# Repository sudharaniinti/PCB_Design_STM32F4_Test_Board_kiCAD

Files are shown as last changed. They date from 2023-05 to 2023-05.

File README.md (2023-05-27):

# STM32F4_based_PCB_Design_using_kiCAD
This repository contains all the files related to the design of a PCB using KICAD. The PCB is based on the STM32F4-based microcontroller and incorporates a USB interface and a Buck converter.

This repository includes the following files:

1. **Schematic (PDF File)**: A detailed PDF file that presents the circuit connections and component arrangement in a clear and concise manner.

2. **Schematic (kiCAD File)**: The original KICAD file of the schematic, allowing for easy editing and customization.

3. **Netlist**: The netlist file, an essential component of the design, which provides information about the electrical connections between various components and ensures accurate signal flow within the PCB.

4. **PCB Design**: The PCB layout file displaying the placement of components, routing traces, and layers used.

5. **Bill of Materials(BOM)**: The BOM file (in CSV format) listing all the components used in the design along with their quantities and specifications.

6. **Gerber Files**: These files (in ZIP format) are necessary for PCB fabrication. They include all the data required by the manufacturer to produce the physical PCB, such as copper layers, solder mask, silkscreen, drill holes, and board outline.

7. **Component Placement File**: This file (in CSV format) provides the precise coordinates and orientations for placing components on the PCB. It assists during the assembly process by ensuring accurate component placement.

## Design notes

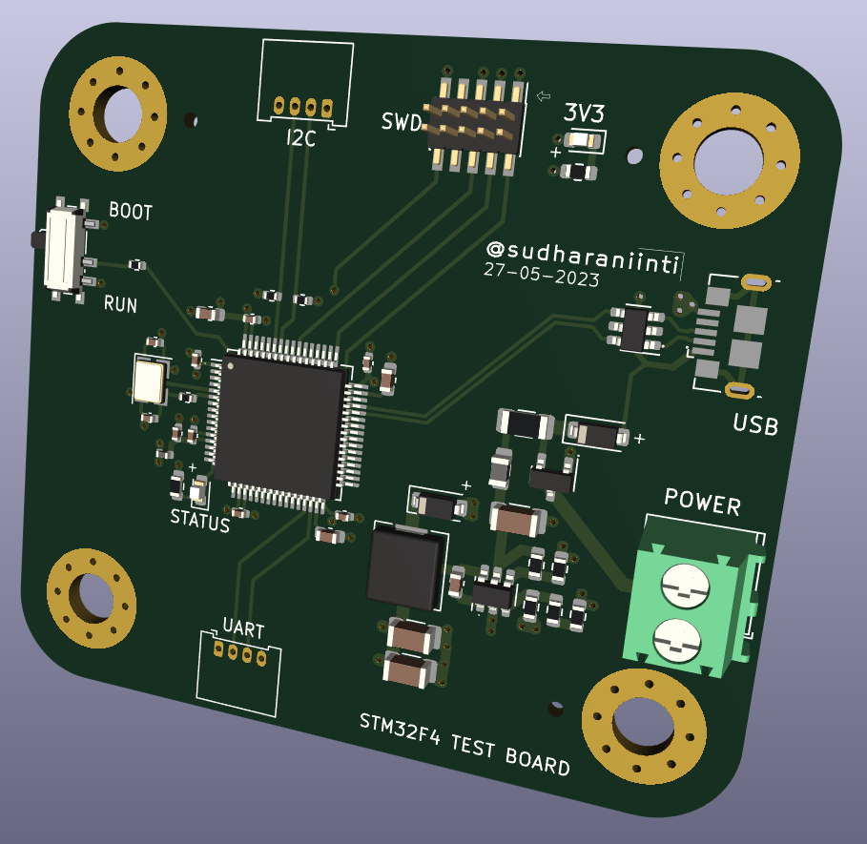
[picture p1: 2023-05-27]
PCB_3D_VIEW_2.png

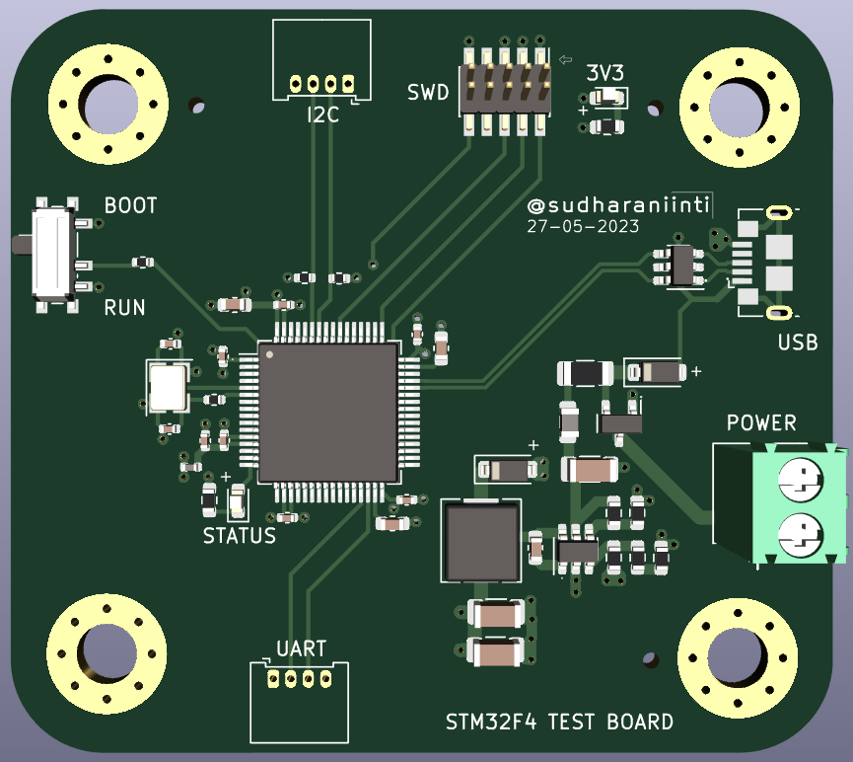
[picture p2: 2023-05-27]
PCB_3D_VIEW_1_.png

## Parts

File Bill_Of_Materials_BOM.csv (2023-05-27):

Source: | E:\KiCAD_STM32\KiCAD_STM32.kicad_sch
Date: | 5/28/2023 2:46:41 AM
Tool: | Eeschema 7.0.2
Generator: | C:\Program Files\KiCad\7.0\bin\scripting\plugins/bom_csv_grouped_by_value.py
Component Count: | 50
Collated Components:
Item | Qty | Reference(s) | Value | LibPart | Footprint | Datasheet | DNP
1 | 2 | C1, C2 | 2.2uF | Device:C_Small | Capacitor_SMD:C_0603_1608Metric | ~
2 | 1 | C3 | 4.7uF | Device:C_Small | Capacitor_SMD:C_0603_1608Metric | ~
3 | 5 | C4, C5, C6, C7, C8 | 100nF | Device:C_Small | Capacitor_SMD:C_0402_1005Metric | ~
4 | 1 | C9 | 1uF | Device:C_Small | Capacitor_SMD:C_0402_1005Metric | ~
5 | 1 | C10 | 10nF | Device:C_Small | Capacitor_SMD:C_0402_1005Metric | ~
6 | 2 | C11, C12 | 12pF | Device:C_Small | Capacitor_SMD:C_0402_1005Metric | ~
7 | 3 | C13, C15, C16 | 10uF | Device:C_Small | Capacitor_SMD:C_1206_3216Metric | ~
8 | 1 | C14 | 10nF | Device:C_Small | Capacitor_SMD:C_0603_1608Metric | ~
9 | 1 | D1 | Blue | Device:LED_Small | LED_SMD:LED_0603_1608Metric | ~
10 | 2 | D2, D3 | B5819W | Device:D_Schottky_Small | Diode_SMD:D_SOD-123 | ~
11 | 1 | D4 | RED | Device:LED_Small | LED_SMD:LED_0603_1608Metric | ~
12 | 1 | F1 | 250mA | Device:Polyfuse_Small | Fuse:Fuse_1206_3216Metric | ~
13 | 1 | FB1 | 600 @ 600MHz | Device:FerriteBead_Small | Inductor_SMD:L_0805_2012Metric | ~
14 | 4 | H1, H2, H3, H4 | MountingHole_Pad | Mechanical:MountingHole_Pad | MountingHole:MountingHole_4.3mm_M4_Pad_Via | ~
15 | 1 | J1 | Screw_Terminal_01x02 | Connector:Screw_Terminal_01x02 | TerminalBlock_Phoenix:TerminalBlock_Phoenix_PT-1,5-2-3.5-H_1x02_P3.50mm_Horizontal | ~
16 | 1 | J2 | SWD | Connector_Generic:Conn_02x05_Odd_Even | Connector_PinHeader_1.27mm:PinHeader_2x05_P1.27mm_Vertical_SMD | ~
17 | 2 | J3, J4 | Conn_01x04 | Connector_Generic:Conn_01x04 | Connector_Molex:Molex_PicoBlade_53048-0410_1x04_P1.25mm_Horizontal | ~
18 | 1 | J5 | USB_B_Micro | Connector:USB_B_Micro | Connector_USB:USB_Micro-B_GCT_USB3076-30-A | ~
19 | 1 | L1 | 39nH | Device:L_Small | Inductor_SMD:L_0402_1005Metric | ~
20 | 1 | L2 | 10uF | Device:L_Small | Inductor_SMD:L_Sunlord_MWSA0518S | ~
21 | 1 | Q1 | AO3401A | Transistor_FET:AO3401A | Package_TO_SOT_SMD:SOT-23 | http://www.aosmd.com/pdfs/datasheet/AO3401A.pdf
22 | 1 | R1 | 10k | Device:R_Small | Resistor_SMD:R_0402_1005Metric | ~
23 | 1 | R2 | 47 | Device:R_Small | Resistor_SMD:R_0402_1005Metric | ~
24 | 1 | R3 | 1.5k | Device:R_Small | Resistor_SMD:R_0603_1608Metric | ~
25 | 1 | R4 | 100k | Device:R_Small | Resistor_SMD:R_0603_1608Metric | ~
26 | 1 | R5 | 68k | Device:R_Small | Resistor_SMD:R_0603_1608Metric | ~
27 | 1 | R6 | 47k | Device:R_Small | Resistor_SMD:R_0603_1608Metric | ~
28 | 1 | R7 | 15k | Device:R_Small | Resistor_SMD:R_0603_1608Metric | ~
29 | 1 | R8 | 270 | Device:R_Small | Resistor_SMD:R_0603_1608Metric | ~
30 | 2 | R9, R10 | 2.2k | Device:R_Small | Resistor_SMD:R_0402_1005Metric | ~
31 | 1 | R11 | 1k | Device:R_Small | Resistor_SMD:R_0603_1608Metric | ~
32 | 1 | SW1 | SW_SPDT | Switch:SW_SPDT | Button_Switch_SMD:SW_SPDT_PCM12 | ~
33 | 1 | U1 | STM32F405RGT6 | MCU_ST_STM32F4:STM32F405RGTx | Package_QFP:LQFP-64_10x10mm_P0.5mm | https://www.st.com/resource/en/datasheet/stm32f405rg.pdf
34 | 1 | U3 | USBLC6-2SC6 | Power_Protection:USBLC6-2SC6 | Package_TO_SOT_SMD:SOT-23-6 | https://www.st.com/resource/en/datasheet/usblc6-2.pdf
35 | 1 | U4 | MP2359 | :MP2359_1 | Package_TO_SOT_SMD:SOT-23-6
36 | 1 | Y1 | 16MHz | Device:Crystal_GND24_Small | Crystal:Crystal_SMD_3225-4Pin_3.2x2.5mm | ~

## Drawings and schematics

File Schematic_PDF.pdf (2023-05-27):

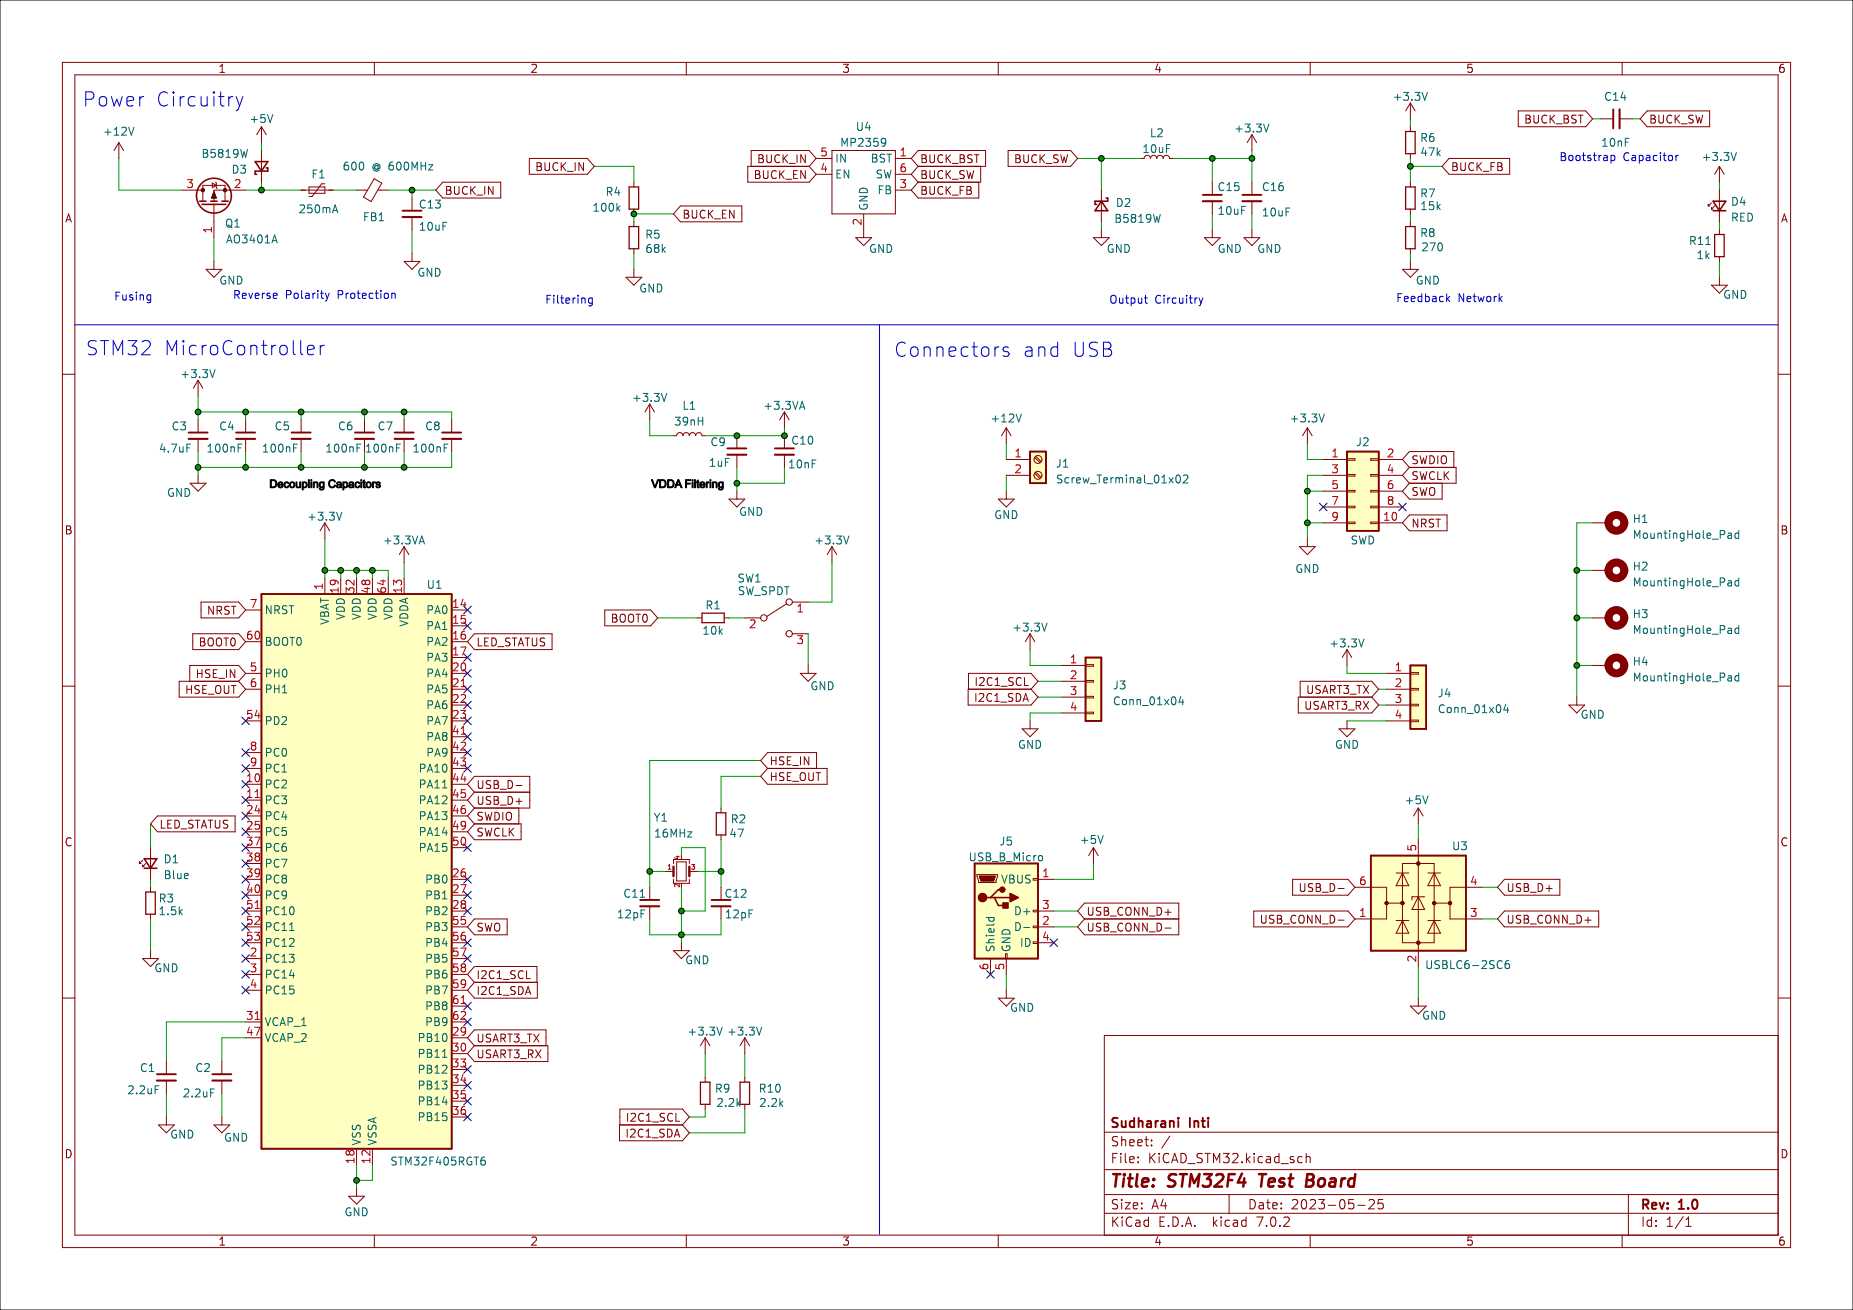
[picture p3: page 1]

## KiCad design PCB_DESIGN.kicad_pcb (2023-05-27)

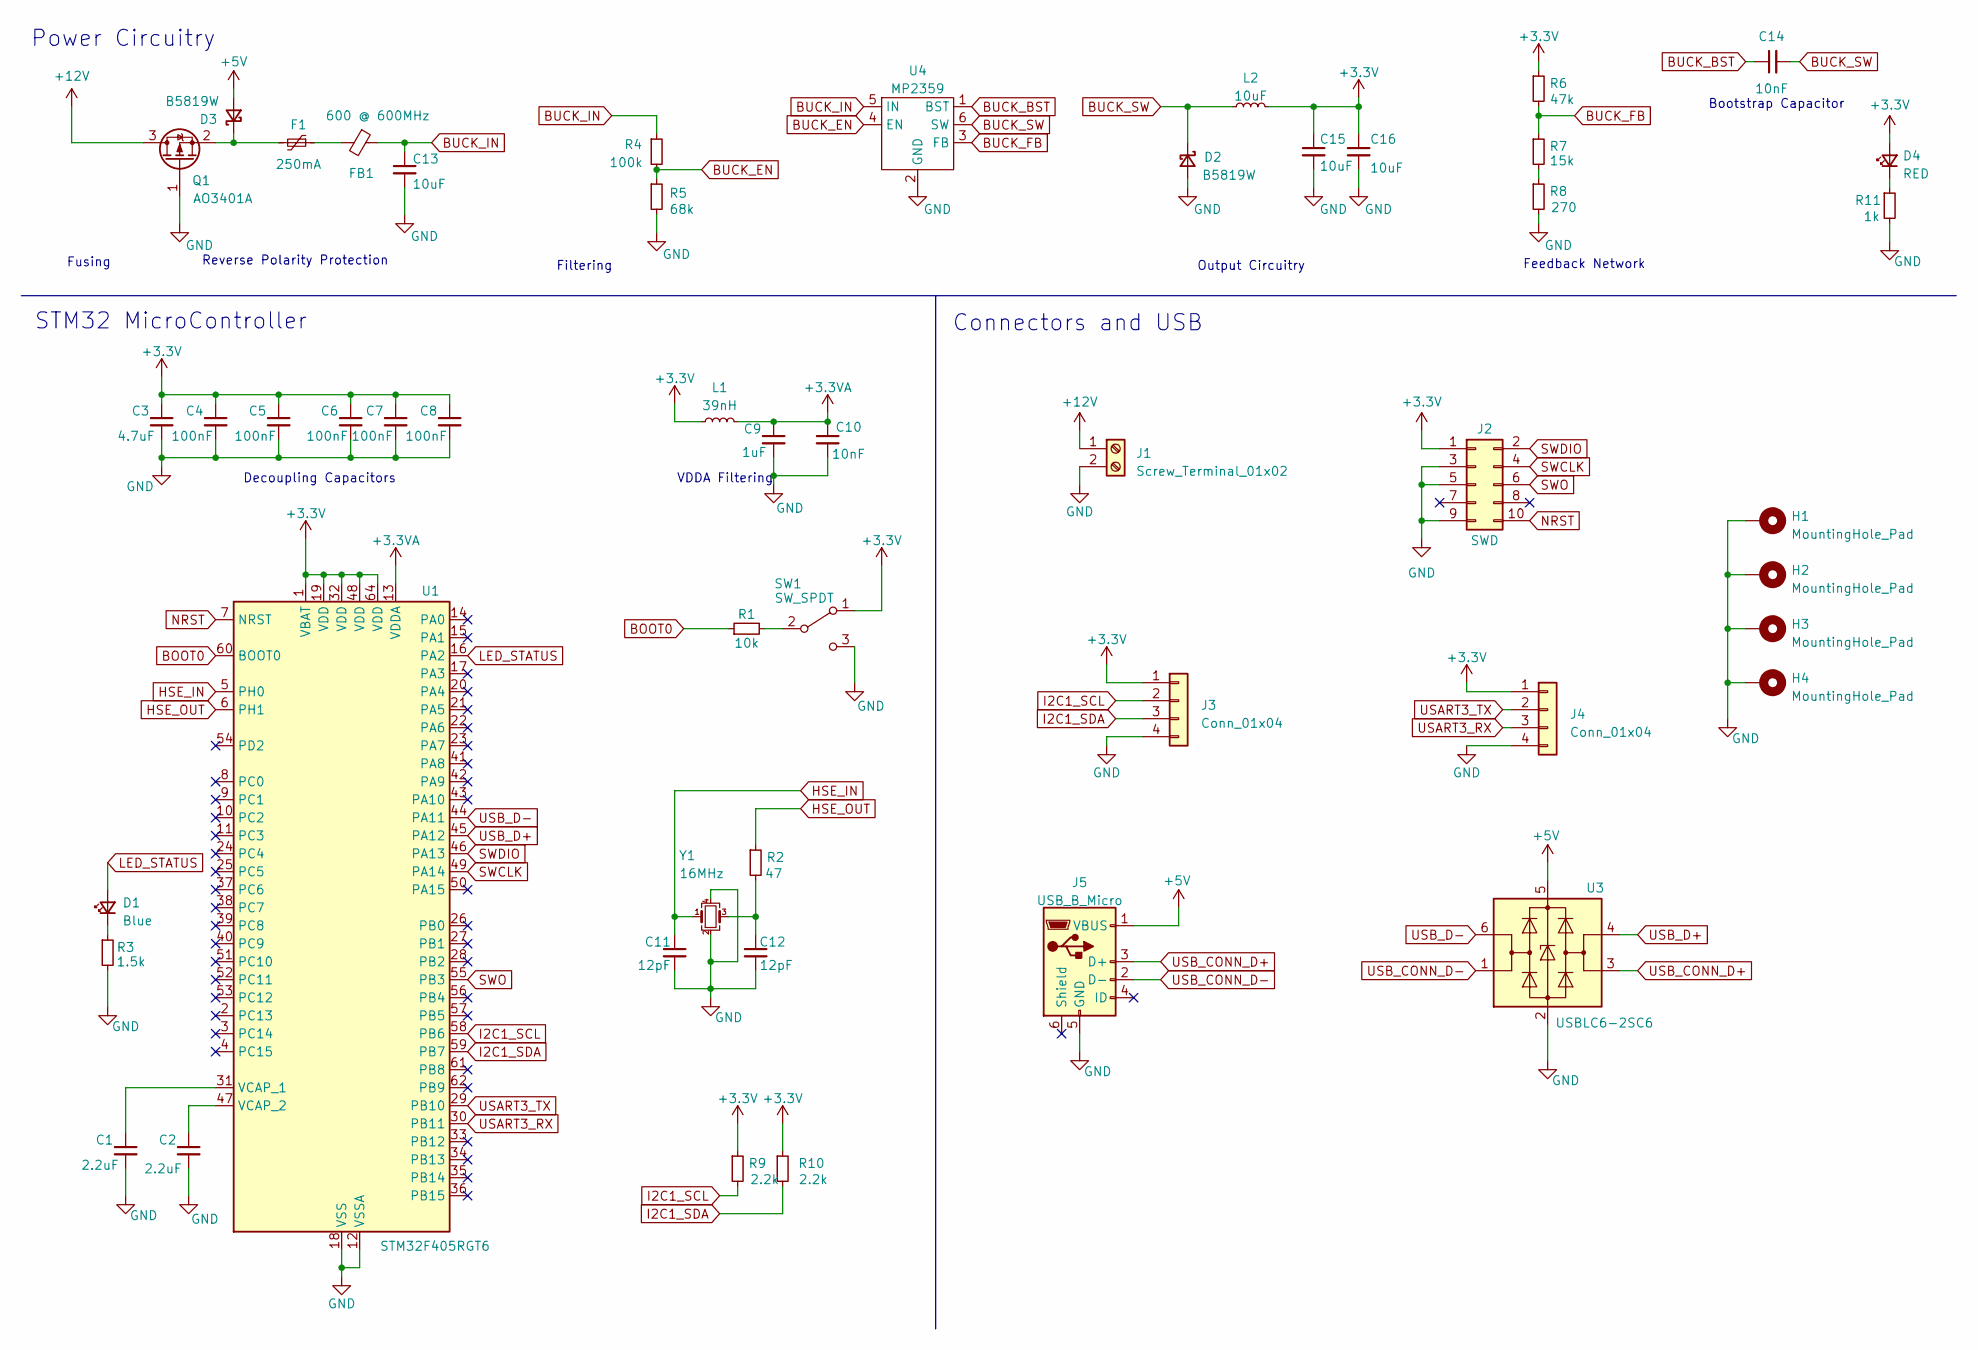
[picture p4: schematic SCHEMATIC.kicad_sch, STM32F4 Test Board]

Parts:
C1, C2: 2.2uF; C_0603_1608Metric
C3: 4.7uF; C_0603_1608Metric
C4, C5, C6, C7, C8: 100nF; C_0402_1005Metric
C9: 1uF; C_0402_1005Metric
C10: 10nF; C_0402_1005Metric
C11, C12: 12pF; C_0402_1005Metric
C13, C15, C16: 10uF; C_1206_3216Metric
C14: 10nF; C_0603_1608Metric
D1: Blue; LED_0603_1608Metric
D2, D3: B5819W; D_SOD-123
D4: RED; LED_0603_1608Metric
F1: 250mA; Fuse_1206_3216Metric
FB1: 600 @ 600MHz; L_0805_2012Metric
H1, H2, H3, H4: MountingHole_Pad; MountingHole_4.3mm_M4_Pad_Via
J1: Screw_Terminal_01x02; TerminalBlock_Phoenix_PT-1,5-2-3.5-H_1x02_P3.50mm_Horizontal
J2: SWD; PinHeader_2x05_P1.27mm_Vertical_SMD
J3, J4: Conn_01x04; Molex_PicoBlade_53048-0410_1x04_P1.25mm_Horizontal
J5: USB_B_Micro; USB_Micro-B_GCT_USB3076-30-A
L1: 39nH; L_0402_1005Metric
L2: 10uF; L_Sunlord_MWSA0518S
Q1: AO3401A; SOT-23
R1: 10k; R_0402_1005Metric
R2: 47; R_0402_1005Metric
R3: 1.5k; R_0603_1608Metric
R4: 100k; R_0603_1608Metric
R5: 68k; R_0603_1608Metric
R6: 47k; R_0603_1608Metric
R7: 15k; R_0603_1608Metric
R8: 270; R_0603_1608Metric
R9, R10: 2.2k; R_0402_1005Metric
R11: 1k; R_0603_1608Metric
SW1: SW_SPDT; SW_SPDT_PCM12
U1: STM32F405RGT6; LQFP-64_10x10mm_P0.5mm
U3: USBLC6-2SC6; SOT-23-6
U4: MP2359; SOT-23-6
Y1: 16MHz; Crystal_SMD_3225-4Pin_3.2x2.5mm

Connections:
+3.3V: C3.1, C4.1, C5.1, C6.1, C7.1, C8.1, C15.1, C16.1, D4.2 (A), J2.1, J3.1, J4.1, L1.1, L2.2, R6.1, R9.1, R10.1, SW1.1 (A), U1.1 (VBAT), U1.19 (VDD), U1.32 (VDD), U1.48 (VDD), U1.64 (VDD)
+3.3VA: C9.1, C10.1, L1.2, U1.13 (VDDA)
+5V: D3.2 (A), J5.1 (VBUS), U3.5 (VBUS)
+12V: J1.1, Q1.3 (D)
BOOT0: R1.1, U1.60 (BOOT0)
BUCK_BST: C14.1, U4.1 (BST)
BUCK_EN: R4.2, R5.1, U4.4 (EN)
BUCK_FB: R6.2, R7.1, U4.3 (FB)
BUCK_IN: C13.1, FB1.1, R4.1, U4.5 (IN)
BUCK_SW: C14.2, D2.1 (K), L2.1, U4.6 (SW)
GND: C1.2, C2.2, C3.2, C4.2, C5.2, C6.2, C7.2, C8.2, C9.2, C10.2, C11.2, C12.2, C13.2, C15.2, C16.2, D2.2 (A), H1.1, H2.1, H3.1, H4.1, J1.2, J2.3, J2.5, J2.9, J3.4, J4.4, J5.5 (GND), Q1.1 (G), R3.2, R5.2, R8.2, R11.2, SW1.3 (C), U1.12 (VSSA), U1.18 (VSS), U1.63 (VSS), U3.2 (GND), U4.2 (GND), Y1.2, Y1.4
HSE_IN: C11.1, U1.5 (PH0), Y1.1
HSE_OUT: R2.1, U1.6 (PH1)
I2C1_SCL: J3.2, R9.2, U1.58 (PB6)
I2C1_SDA: J3.3, R10.2, U1.59 (PB7)
LED_STATUS: D1.2 (A), U1.16 (PA2)
NRST: J2.10, U1.7 (NRST)
unnamed: C12.1, R2.2, Y1.3
unnamed: D1.1 (K), R3.1
unnamed: D3.1 (K), F1.2, Q1.2 (S)
unnamed: D4.1 (K), R11.1
unnamed: F1.1, FB1.2
unnamed: R7.2, R8.1
unnamed: R1.2, SW1.2 (B)
unnamed: C1.1, U1.31 (VCAP_1)
unnamed: C2.1, U1.47 (VCAP_2)
SWCLK: J2.4, U1.49 (PA14)
SWDIO: J2.2, U1.46 (PA13)
SWO: J2.6, U1.55 (PB3)
USART3_RX: J4.3, U1.30 (PB11)
USART3_TX: J4.2, U1.29 (PB10)
USB_CONN_D+: J5.3 (D+), U3.3 (I/O2)
USB_CONN_D-: J5.2 (D-), U3.1 (I/O1)
USB_D+: U1.45 (PA12), U3.4 (I/O2)
USB_D-: U1.44 (PA11), U3.6 (I/O1)

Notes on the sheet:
Decoupling Capacitors
Filtering
Fusing
Output Circuitry
Power Circuitry
VDDA Filtering
Feedback Network
Connectors and USB
STM32 MicroController
Reverse Polarity Protection
Bootstrap Capacitor

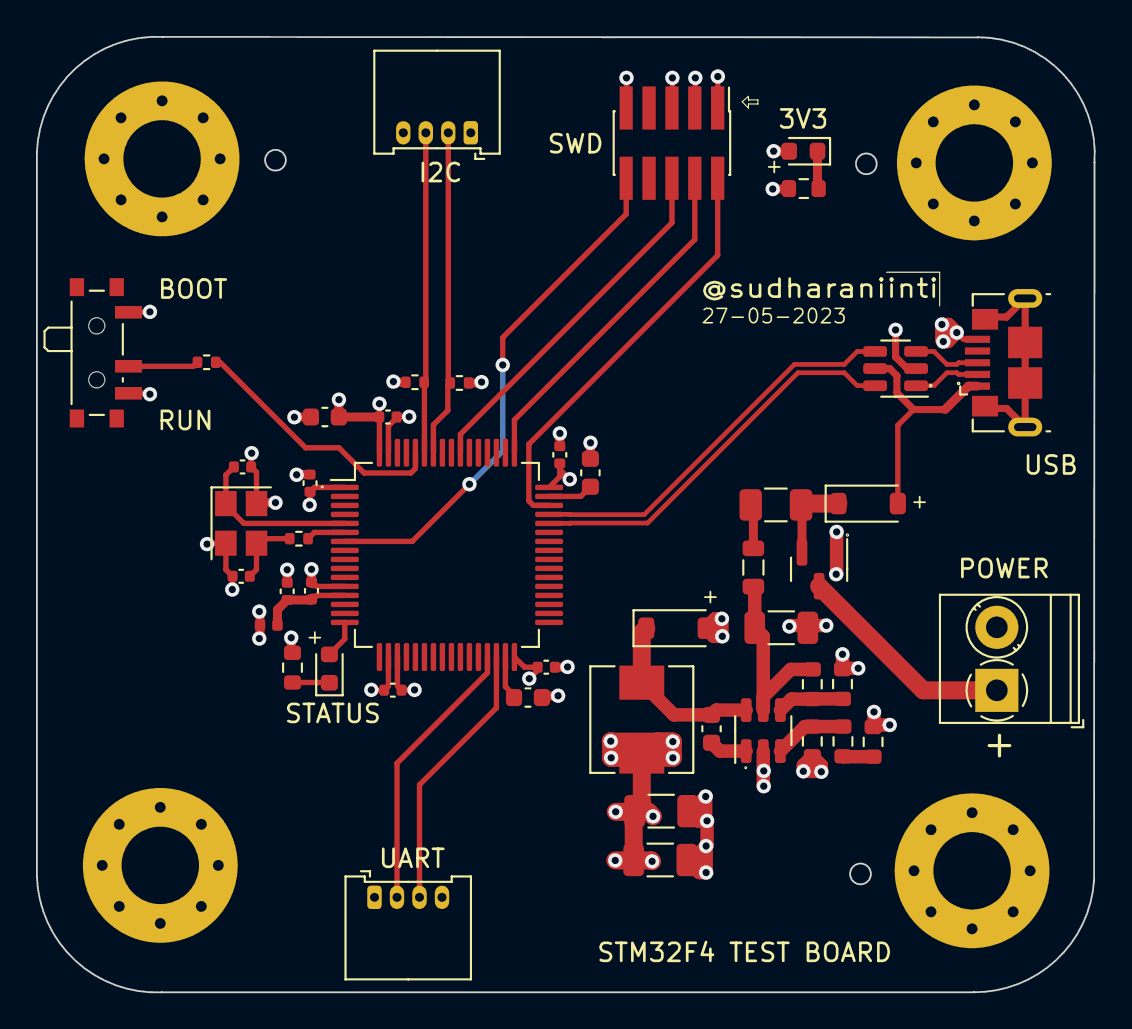
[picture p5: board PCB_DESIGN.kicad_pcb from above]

Board: 4 copper layers, 58.8 x 53.1 mm, 50 parts (0 on the bottom side), 35 nets.
